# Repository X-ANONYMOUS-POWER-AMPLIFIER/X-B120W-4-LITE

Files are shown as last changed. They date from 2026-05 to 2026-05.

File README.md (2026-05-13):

# X-B120W-4-LITE - SIMPLE MAIN-CIRCUIT MODULE OF 120 WATTS CLASS-B AUDIO POWER AMPLIFIER MAIN-CIRCUIT FOR 4-OHMS OUTPUT LOAD

X-B120W-4-LITE is a power amplifier main-circuit module designed to be simple, with only few number of transistors within its input-stage and its VAS, designed to be fit in a small size single-sided circuit board. It is designed to handle 120 watts of 4-ohms output load power rating.

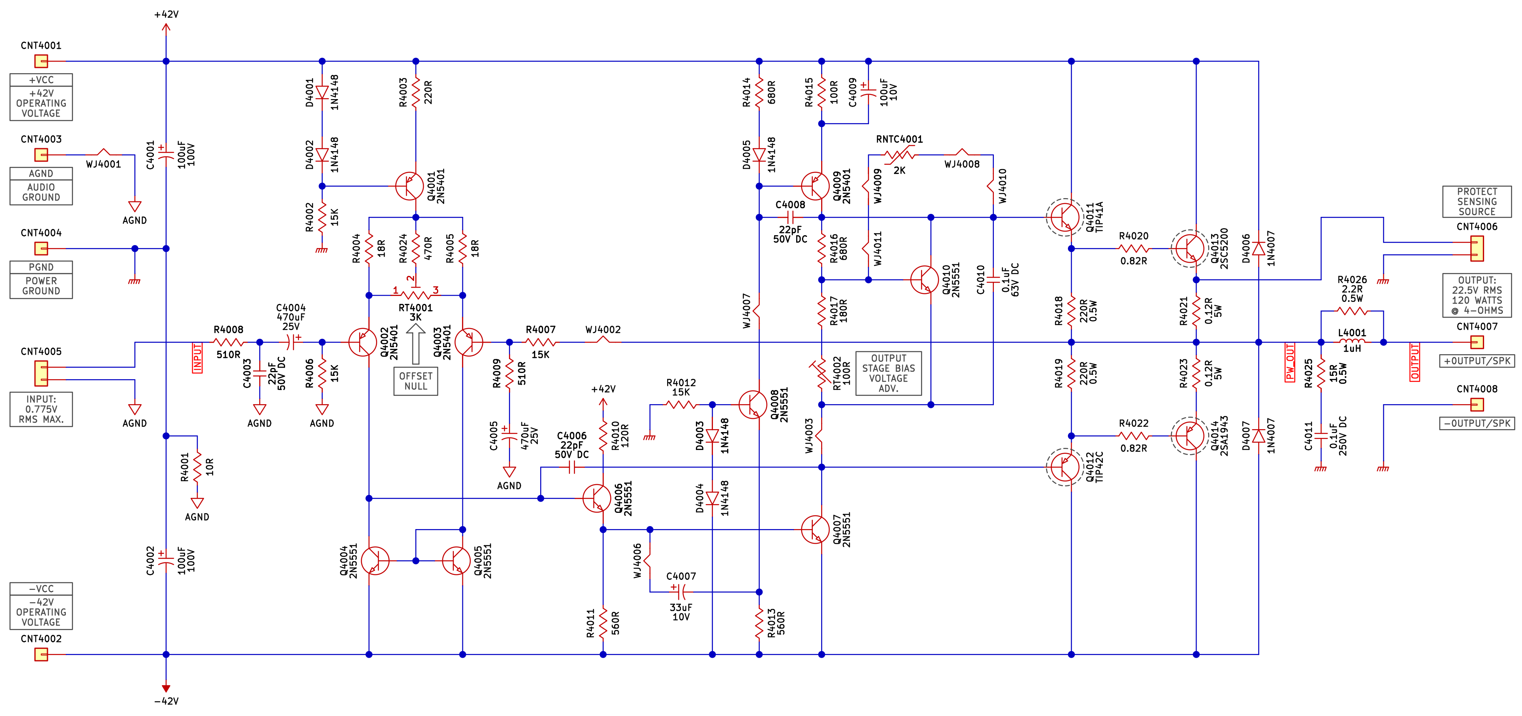
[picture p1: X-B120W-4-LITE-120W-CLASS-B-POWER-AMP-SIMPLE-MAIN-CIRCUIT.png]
X-B120W-4 schematic diagram


The circuit of X-B120W-4-LITE applies only the effective circuitry models for each of its blocks. Its input-stage applies a minimalist-but-effective LTP (Long Tailed Pair) circuit model, completed with an active-load and an offset null adjustment trimmer. Its VAS (Voltage Amplifier Stage) applies a simple circuit model but with an advanced active-load technique to achieve high amplification performance, with applies only few number of transistors without needing to apply differential-based topology.

## Advanced VAS Model

The VAS of this power amp main-circuit model has an active load that synchronized with the main VAS side to be working as well a fully symmetrical VAS. The output signal from the LTP buffer (Q4006's emitter) copied by a grounded-base transistor amplifier or signal-current-buffer, Q4008, to feed a copy of signal for VAS's loader, Q4009, makes the VAS's loader to be fully actively working side-by-side with the main VAS, Q4007.

The amplification workflow between LTP buffer, Q4006, into the VAS loader, Q4009, isn't for tackling the DC amplification, but limited for tackling AC amplification. The LTP buffer output, Q4006's emitter, is coupled by C4007 into the emitter of Q4008 for gaining the AC signal only, thus Q4008 can keep its main function as a current-source to provide a constant forward-bias-current for Q4009's base and thus Q4009 also kept its function as a current-source for providing the initial constant forward-bias-current for the output-stage while it is also taking function as an active loader of VAS for providing fully symmetrical AC amplification.

By applying this technique, this power amp main-circuit model will be able to achieve wide headroom even for 1-ohms load in fully symmetrically and certainly achieve high performance in nominal output load (4-ohms or 8-ohms). And certainly, one of the important tings is about limit the number of transistors, makes the X-B120W-4-LITE circuit model quit simple with high performance guarantee.

## Warning: None of Current-Limiter Applied Within The Output-Stage

There is none of current-limiter applied within the output-stage, means that it may introduce a risk of short-circuited output. To prevent a fatal output short-circuited overcome, an output protection circuit have to be applied between the X-B120W-4-LITE module's +SPK output and the loudspeaker. The sensing signal of the overload output or output short-circuit can be obtained via CNT4006.

You may have a question, why none of current-limiter applied within the output-stage? The answer is: Applying the current-limiters within the output-stage, as it commonly applied "just to drop the signal amplitude of the output-stage driver transistor bases" - is not really effective since the VAS will always maintain its signal-current along to follow its amplification level although the current-limiter actives as it detects a short-circuited output.

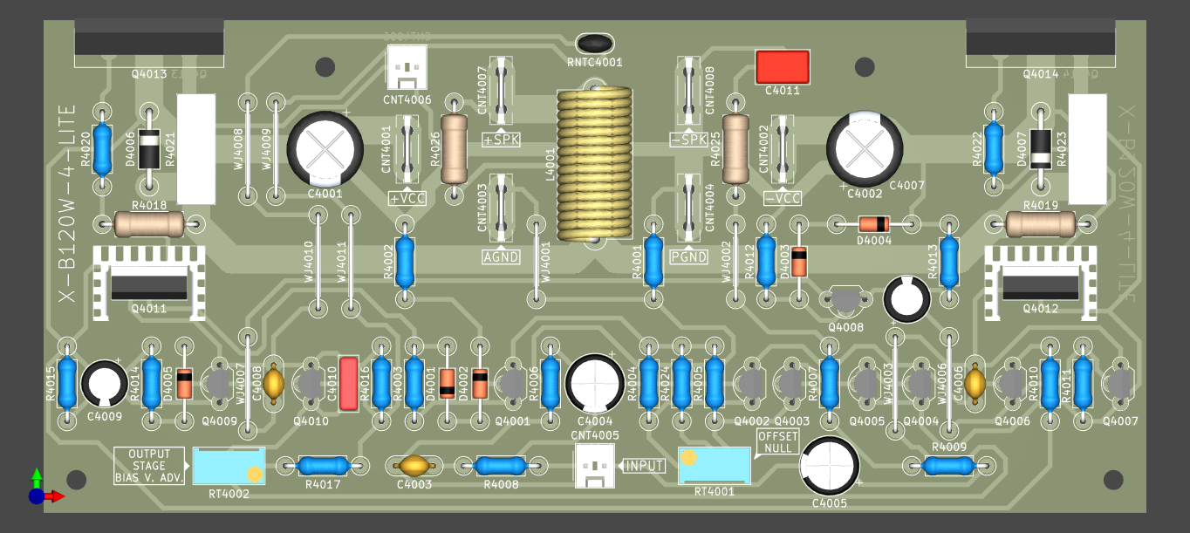
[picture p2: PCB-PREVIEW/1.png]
Circuit board preview 1

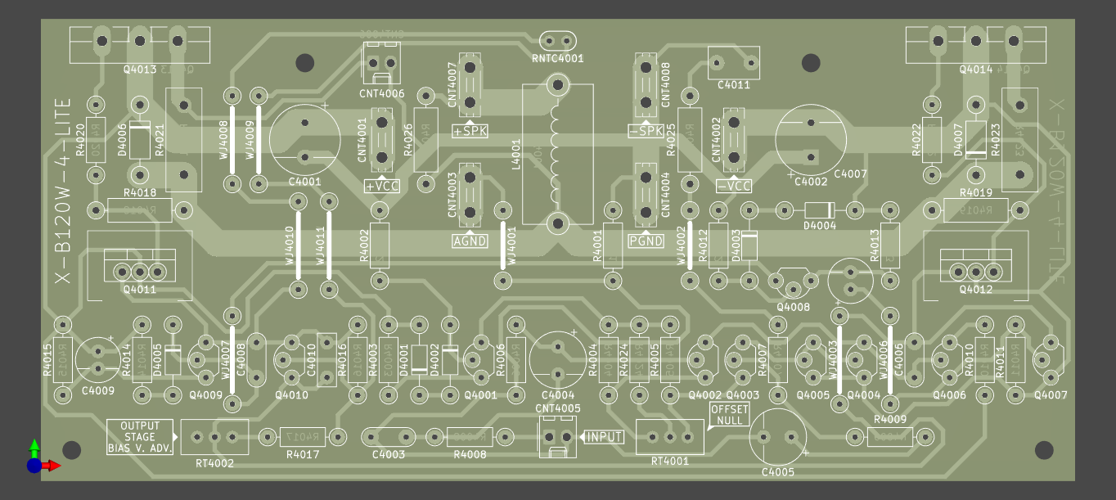
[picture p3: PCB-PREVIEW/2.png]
Circuit board preview 2

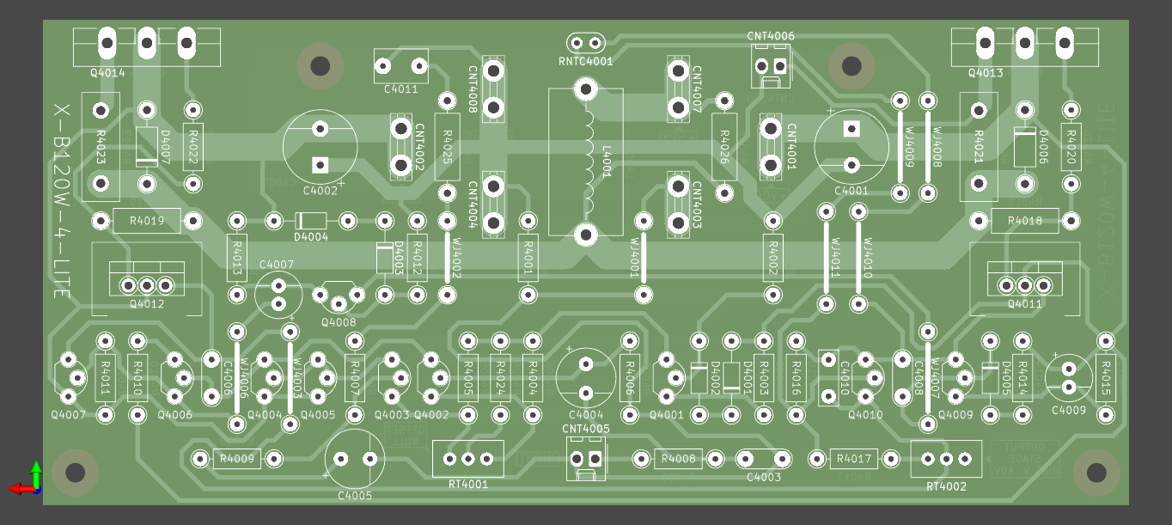
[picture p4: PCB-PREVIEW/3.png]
Circuit board preview 3

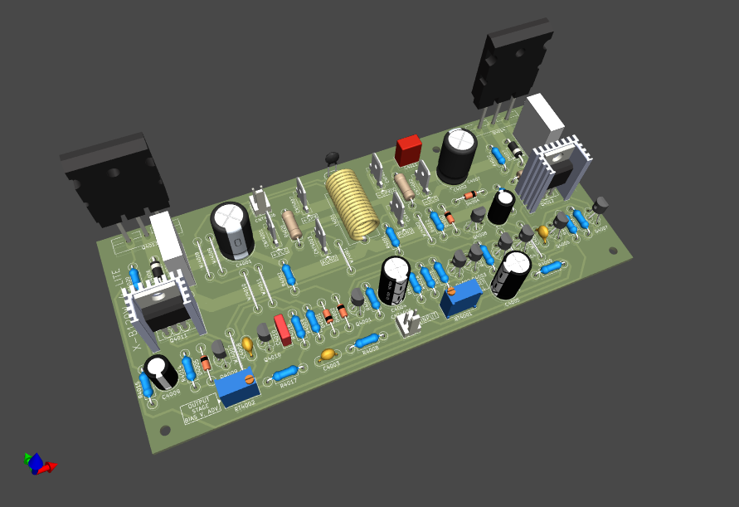
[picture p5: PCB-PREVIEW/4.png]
Circuit board preview 4

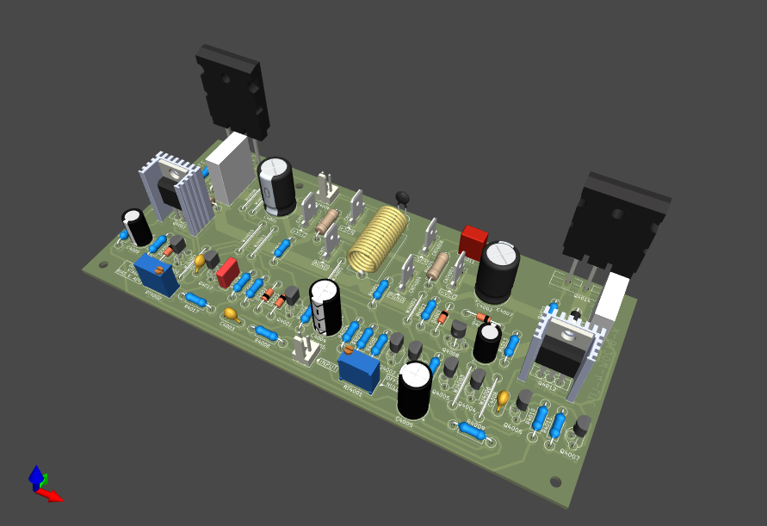
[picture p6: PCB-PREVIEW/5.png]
Circuit board preview 5


## License

1. **License Grant**  
The Licensor hereby grants you a worldwide, royalty-free, non-exclusive, perpetual license to use the circuit design for the non-commercial purposes only.
2. **Conditions**  
Attribution: You must provide credit to the original creator when distributing this circuit design.
3. **Disclaimer of Warranty**  
THE DESIGN IS PROVIDED "AS IS". THE LICENSOR MAKES NO WARRANTIES, EXPRESS OR IMPLIED, REGARDING THE DESIGN, INCLUDING BUT NOT LIMITED TO ANY IMPLIED WARRANTIES OF MERCHANTABILITY OR FITNESS FOR A PARTICULAR PURPOSE.
4. **Limitation of Liability**  
IN NO EVENT SHALL THE LICENSOR BE LIABLE FOR ANY DAMAGES, INCLUDING BUT NOT LIMITED TO DIRECT, INDIRECT, INCIDENTAL, OR CONSEQUENTIAL DAMAGES ARISING OUT OF THE USE OF THE DESIGN.

# Design Files Bundle Download

Design files bundle is available for download by follow the URL: [https://github.com/X-ANONYMOUS-POWER-AMPLIFIER/X-B120W-4-LITE/archive/refs/heads/main.zip](https://github.com/X-ANONYMOUS-POWER-AMPLIFIER/X-B120W-4-LITE/archive/refs/heads/main.zip)

The main design files of schematic and PCB design are in [KiCad](https://www.kicad.org/) V.9.x format.

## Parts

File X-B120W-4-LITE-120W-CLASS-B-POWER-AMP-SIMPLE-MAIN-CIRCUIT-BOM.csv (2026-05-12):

Reference | Value | Rating | Description | MFR Number | Manufacturer | Qty
C4001,C4002 | 100uF | 100V | Aluminum Electrolytic Capacitors - Radial Leaded 100uF 100V | ECA-1EM100I | Panasonic | 2
C4003,C4006,C4008 | 22pF | 50V DC | Multilayer Ceramic Capacitors MLCC - Leaded 22PF 50V 5% 5.0MM | RDE5C1H220J0K1H03B | Murata | 3
C4004,C4005 | 470uF | 25V | Aluminum Electrolytic Capacitors - Radial Leaded 470uF 25V | EEU-FC1E471L | Panasonic | 2
C4007 | 33uF | 10V | Aluminum Electrolytic Capacitors - Radial Leaded 10VDC 33uF POLARIZED | ECE-A1AKS330I | Panasonic | 1
C4009 | 100uF | 10V | Aluminum Electrolytic Capacitors - Radial Leaded 100uF 10V | ECE-A1AKA101 | Panasonic | 1
C4010 | 0.1uF | 63V DC | Film Capacitors 0.1 uF 63 VDC 5% | MKS2C031001A00JI00 | WIMA | 1
C4011 | 0.1uF | 250V DC | Film Capacitors 0.1 uF 250 VDC 20% | MKS2F031001E00MSSD | WIMA | 1
CNT4001,CNT4002,CNT4003,CNT4004,CNT4007,CNT4008 | 2376582-2 |  | 250 FASTON PCB TAB TPBR | 2376582-2 | TE Connectivity | 6
CNT4005,CNT4006 | 22-27-2021 |  | Headers & Wire Housings 2 POS HEADER | 22-27-2021 | Molex | 2
D4001,D4002,D4003,D4004,D4005 | 1N4148 |  | Small Signal Switching Diodes Small Signal Diode, DO-35, 100V, 0.2A, 175C | 1N4148 | Diotec Semiconductor | 5
D4006,D4007 | 1N4007 |  | Rectifiers Diode, DO-41, 1000V, 1A | 1N4007 | Diotec Semiconductor | 2
L4001 | 1uH |  | Air Core Inductor, 16 windings, D = 8 mm, enameled wire diameter = 1.2 mm |  |  | 1
Q4001,Q4002,Q4003,Q4009 | 2N5401 |  | Bipolar Transistors - BJT PNP 160Vcbo 150Vceo 5.0Vebo 600mA 625mW | 2N5401 TIN/LEAD | Central Semiconductor | 4
Q4004,Q4005,Q4006,Q4007,Q4008,Q4010 | 2N5551 |  | Bipolar Transistors - BJT NPN 180Vcbo 160Vceo 6.0Vebo 600mA 625mW\ | 2N5551 TIN/LEAD | Central Semiconductor | 6
Q4011 | TIP41A |  | Bipolar Transistors - BJT 6A 100V 65W NPN | TIP41C | STMicroelectronics | 1
Q4012 | TIP42C |  | Bipolar Transistors - BJT 6A 100V 65W PNP | TIP42C | STMicroelectronics | 1
Q4013 | 2SC5200 |  | Bipolar Transistors - BJT NPN 230V 15A | 2SC5200-O(Q) | Toshiba | 1
Q4014 | 2SA1943 |  | Bipolar Transistors - BJT PNP 230V 15A | 2SA1943-O(Q) | Toshiba | 1
R4001 | 10R | 0.25W | Metal Film Resistors - Through Hole 10 OHM 1/4W 1% | MFR-25FRE52-10R | YAGEO | 1
R4002,R4006,R4007,R4012 | 15K | 0.25W | Metal Film Resistors - Through Hole 15K OHM 1/4W 1% | MFR-25FRE52-15K | YAGEO | 4
R4003 | 220R | 0.25W | Metal Film Resistors - Through Hole 220 OHM 1/4W 1% | MFR-25FRE52-220R | YAGEO | 1
R4004,R4005 | 18R | 0.25W | Metal Film Resistors - Through Hole 18 OHM 1/4W 1% | MFR-25FRE52-18R | YAGEO | 2
R4008,R4009 | 510R | 0.25W | Metal Film Resistors - Through Hole 510 OHM 1/4W 1% | MFR-25FRE52-510R | YAGEO | 2
R4010 | 120R | 0.25W | Metal Film Resistors - Through Hole 120 OHM 1/4W 1% | MFR-25FRE52-120R | YAGEO | 1
R4011,R4013 | 560R | 0.25W | Metal Film Resistors - Through Hole 560 OHM 1/4W 1% | MFR-25FRE52-560R | YAGEO | 2
R4014,R4016 | 680R | 0.25W | Metal Film Resistors - Through Hole 680 OHM 1/4W 1% | MFR-25FRE52-680R | YAGEO | 2
R4015 | 100R | 0.25W | Metal Film Resistors - Through Hole 100 OHM 1/4W 1% | MFR-25FRE52-100R | YAGEO | 1
R4017 | 180R | 0.25W | Metal Film Resistors - Through Hole 180 OHM 1/4W 1% | MFR-25FRE52-180R | YAGEO | 1
R4018,R4019 | 220R | 0.5W | Metal Film Resistors - Through Hole 220 OHM 1/5W 1% | MFR-50FTE52-220R | YAGEO | 2
R4020,R4022 | 0.82R | 0.25W | Metal Oxide Resistors RSS1/2 .82 5%TR | MOSX1/2CT52RR82J | KOA Speer | 2
R4021,R4023 | 0.12R | 5W | Current Sense Resistors - Through Hole 0.12 Ohm 5W 5% 350ppm | BPR58CR12J | KOA Speer | 2
R4024 | 470R | 0.25W | Metal Film Resistors - Through Hole 510 OHM 1/4W 1% | MFR-25FRE52-510R | YAGEO | 1
R4025 | 15R | 0.5W | Metal Film Resistors - Through Hole 15 OHM 1/5W 1% | MFR-50FTE52-15R | YAGEO | 1
R4026 | 2.2R | 0.5W | Metal Film Resistors - Through Hole 2.2 OHM 1/5W 1% | MFR-50FTE52-2R2 | YAGEO | 1
RNTC4001 | 2K |  | NTC Thermistors 2Kohm/2% 3528/0.5% | NTCLE100E3202GB0A | Vishay / BC Components | 1
RT4001 | 3K |  | Trimmer Resistors - Through Hole 3/8" 3Kohms Sealed Vertical Adjust | 3296W-1-302ALF | Bourns | 1
RT4002 | 100R |  | Trimmer Resistors - Through Hole 3/8" 100 ohms Sealed Vertical Adjust | 3296W-1-101ALF | Bourns | 1
WJ4001,WJ4002,WJ4003,WJ4006,WJ4007,WJ4008,WJ4009,WJ4010,WJ4011 | Wire Jumper |  | Wire Jumper |  |  | 9

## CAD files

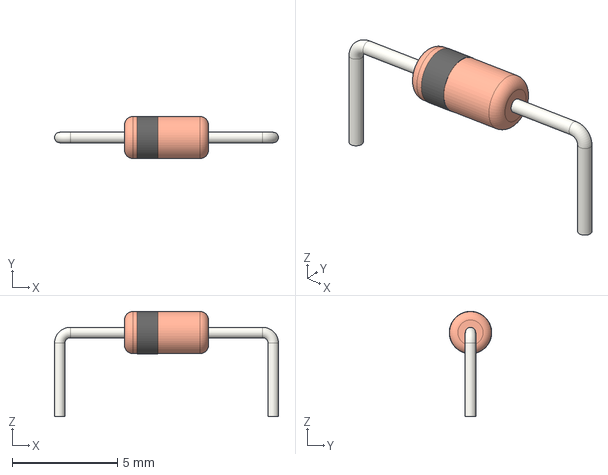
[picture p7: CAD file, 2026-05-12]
3D-FOOTPRINTS/D_DO-35_SOD27_P10.16mm_Horizontal.step
10.7 x 2.02 x 5.01 mm

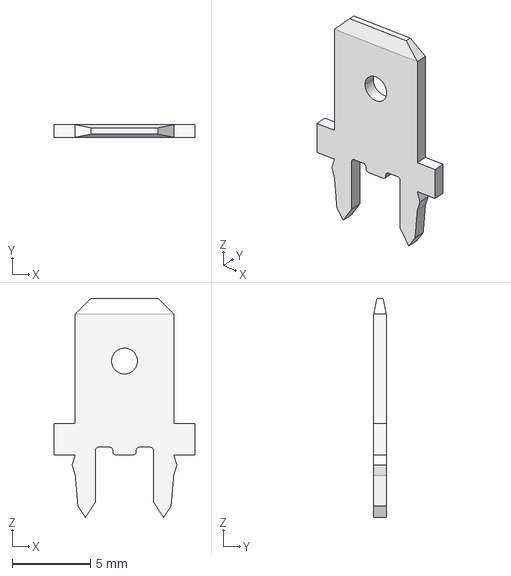
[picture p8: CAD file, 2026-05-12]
3D-FOOTPRINTS/c-2376582-2-a-3d.stp
9.00 x 0.8 x 14.0 mm

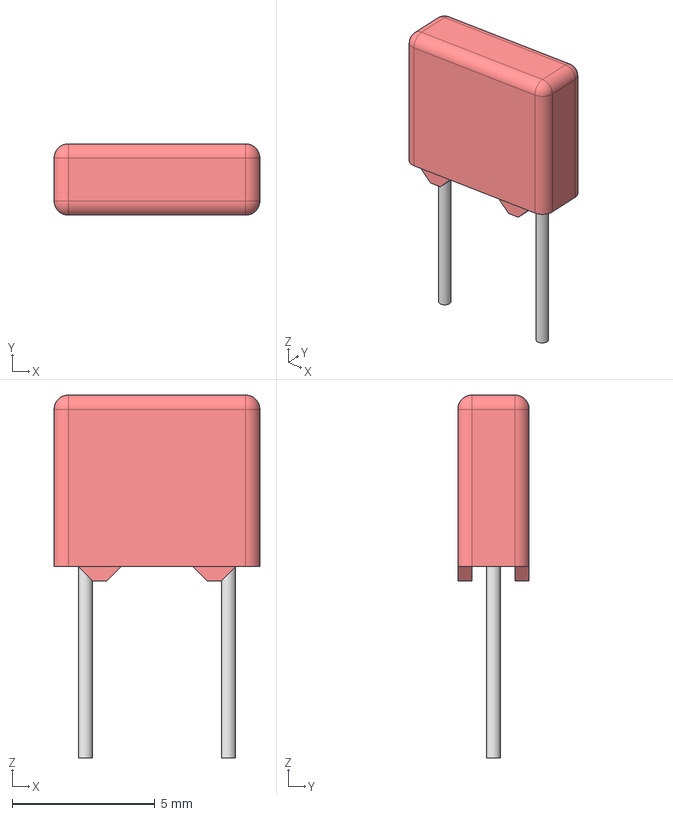
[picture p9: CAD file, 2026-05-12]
3D-FOOTPRINTS/FILM_RED_P500L720W250H650PD50.step
7.20 x 2.50 x 12.7 mm

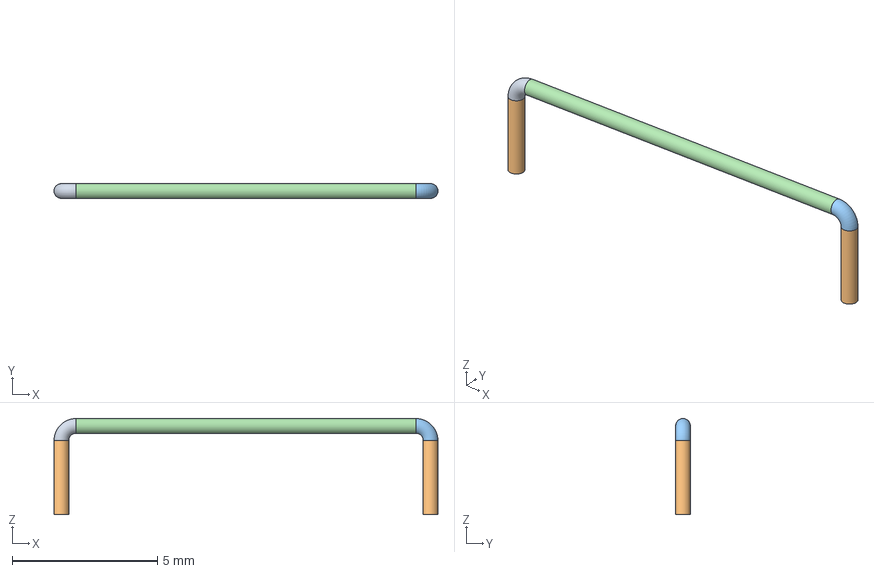
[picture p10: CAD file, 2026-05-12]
3D-FOOTPRINTS/J_12.7mm.step
13.2 x 0.508 x 3.30 mm

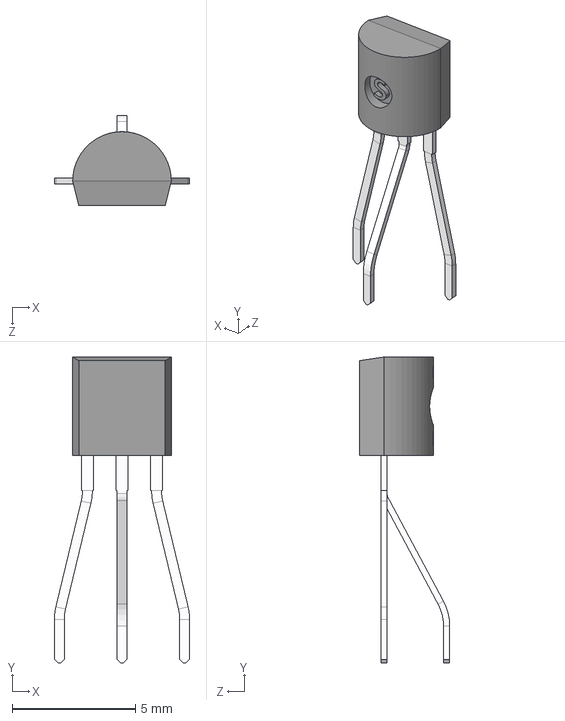
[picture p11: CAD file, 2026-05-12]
3D-FOOTPRINTS/TO-92.STEP
5.48 x 12.4 x 3.66 mm

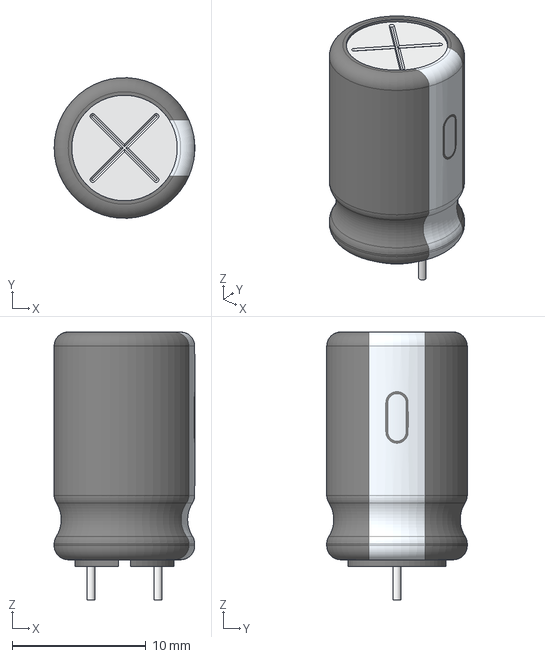
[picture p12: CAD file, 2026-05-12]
3D-FOOTPRINTS/CAP_RAD_D10x16_POL_BK.stp
10.5 x 10.5 x 20.0 mm

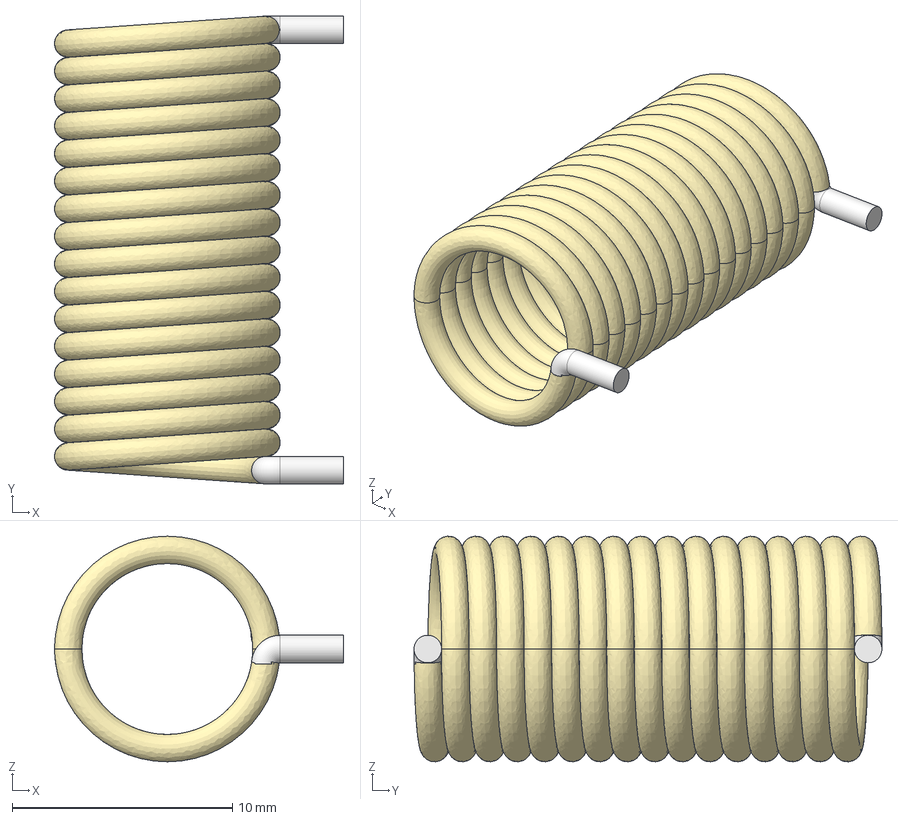
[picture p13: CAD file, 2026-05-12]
3D-FOOTPRINTS/INDUCTOR_AIR_CORE_1uH.step
13.1 x 21.2 x 10.2 mm
Slice.0

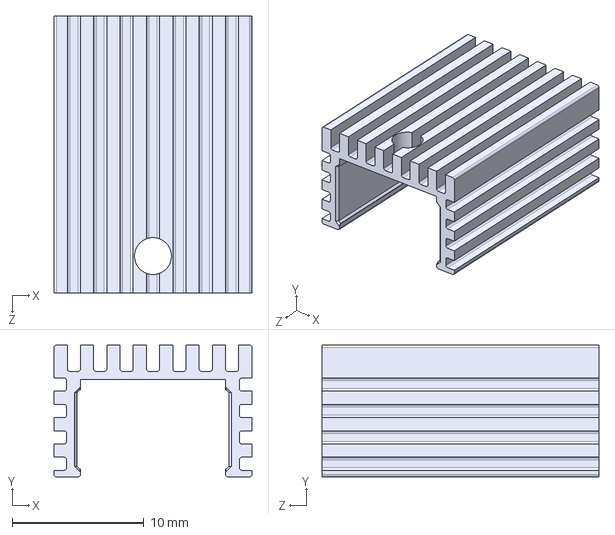
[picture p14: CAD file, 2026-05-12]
3D-FOOTPRINTS/TO220 Heatsink.STEP
15.0 x 10.0 x 21.0 mm

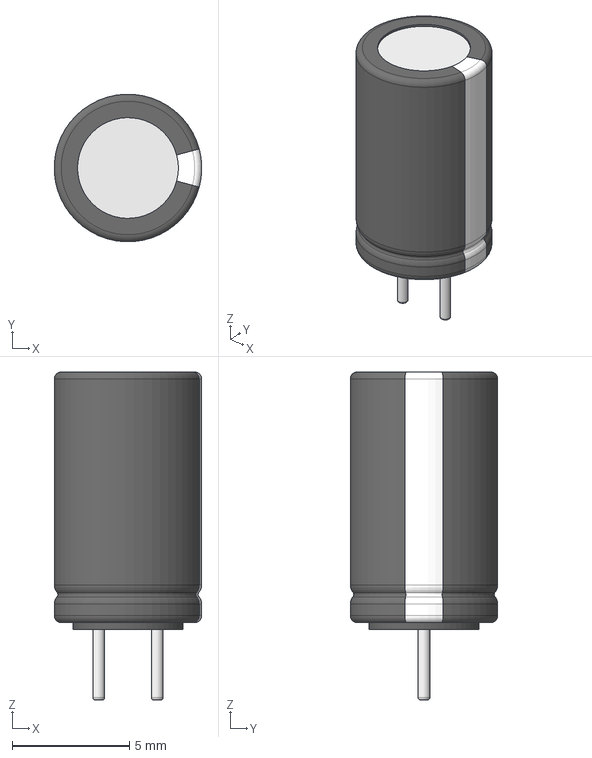
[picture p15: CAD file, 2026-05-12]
3D-FOOTPRINTS/Aluminum_electrolytic_capacitor_radial_D6.3_H11_PinD0.5_Pitch2.5_nominal_black.step
6.29 x 6.30 x 14.0 mm

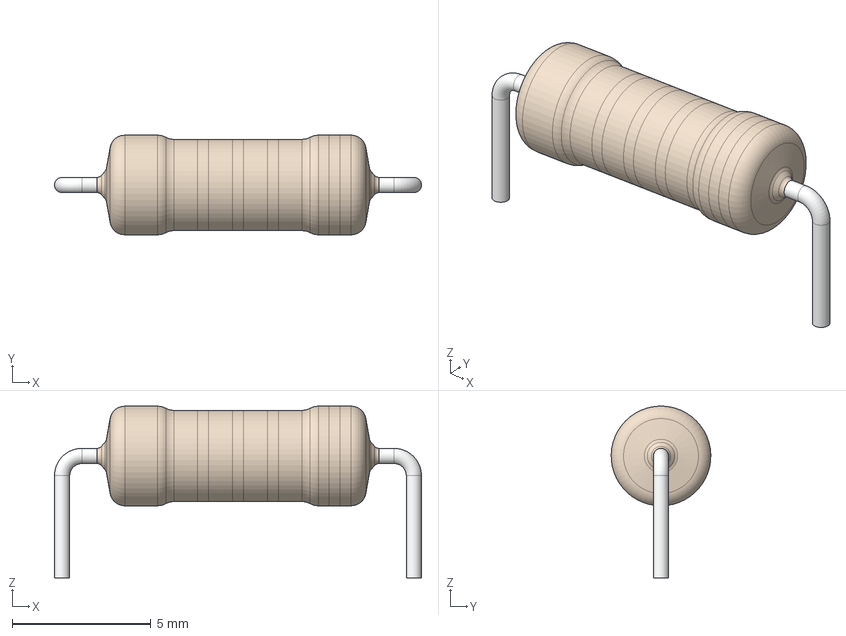
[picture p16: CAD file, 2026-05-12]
3D-FOOTPRINTS/RES-0.5W-H-MO.stp
13.2 x 3.60 x 6.20 mm
RES-0.5W-H-MO
RES-0.5W-H-MO001
RES-0.5W-H-MO002

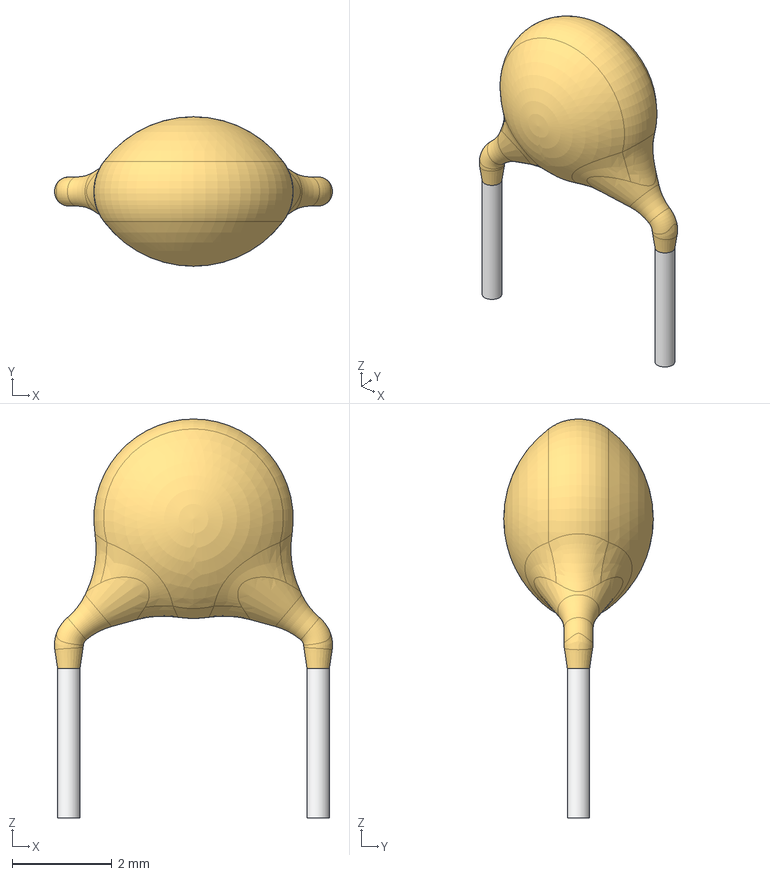
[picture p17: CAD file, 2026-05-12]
3D-FOOTPRINTS/CAP_DISC_4x3_YL.stp
5.58 x 3.00 x 8.00 mm
CAP_DISC_4x3_YL
CAP_DISC_4x3_YL001
CAP_DISC_4x3_YL002

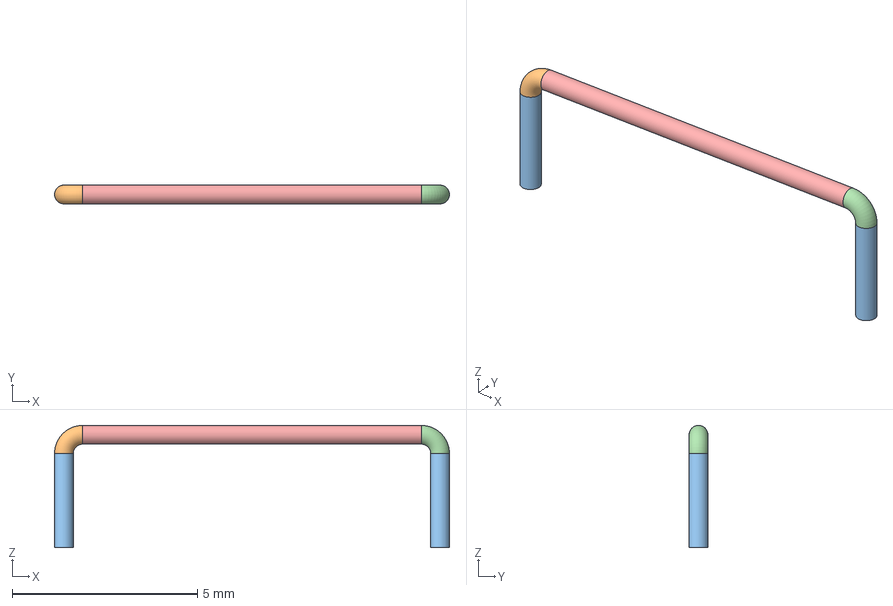
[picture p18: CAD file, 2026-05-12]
3D-FOOTPRINTS/J_10.16mm.step
10.7 x 0.508 x 3.30 mm
Circle
Arc
Circle003
Line
Circle004
Arc001
Circle005
Line002
Circle002
Line001

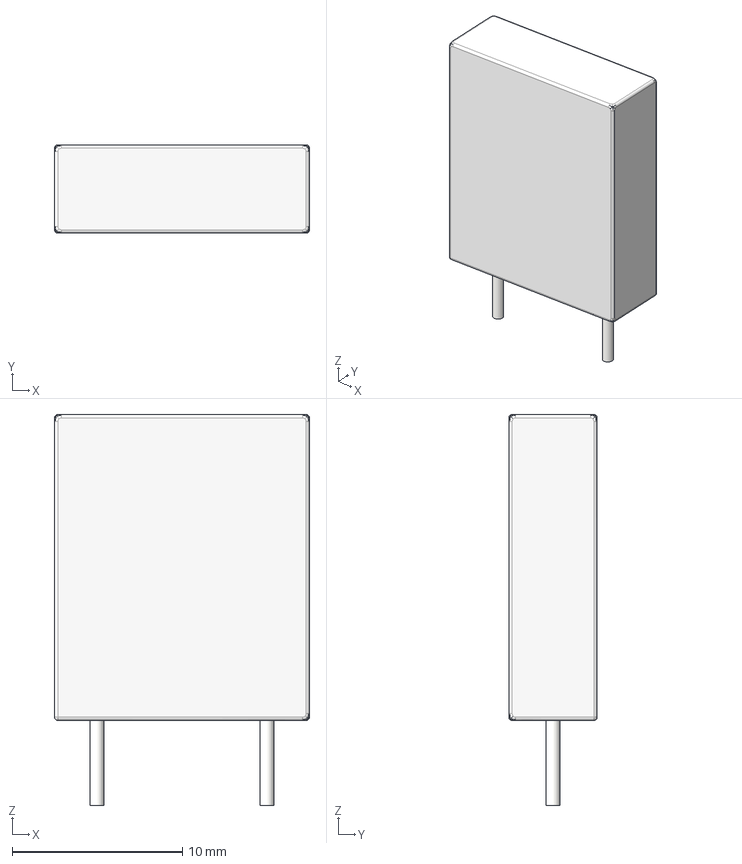
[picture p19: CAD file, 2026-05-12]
3D-FOOTPRINTS/BPR-cement-resistor.step
15.0 x 5.20 x 23.0 mm

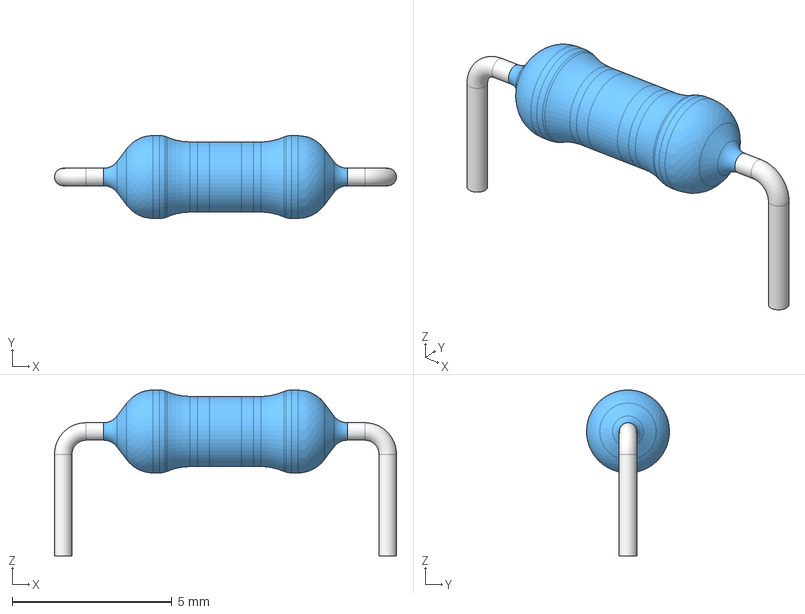
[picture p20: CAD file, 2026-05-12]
3D-FOOTPRINTS/RES-0.25W-H-CF.stp
10.7 x 2.60 x 5.20 mm
RES-0.25W-H-CF
RES-0.25W-H-CF001
RES-0.25W-H-CF002

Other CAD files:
3D-FOOTPRINTS/NTC.step
3D-FOOTPRINTS/470uF 25V electr 8 x16mm -P.diameter 4mm-Black-White.stp

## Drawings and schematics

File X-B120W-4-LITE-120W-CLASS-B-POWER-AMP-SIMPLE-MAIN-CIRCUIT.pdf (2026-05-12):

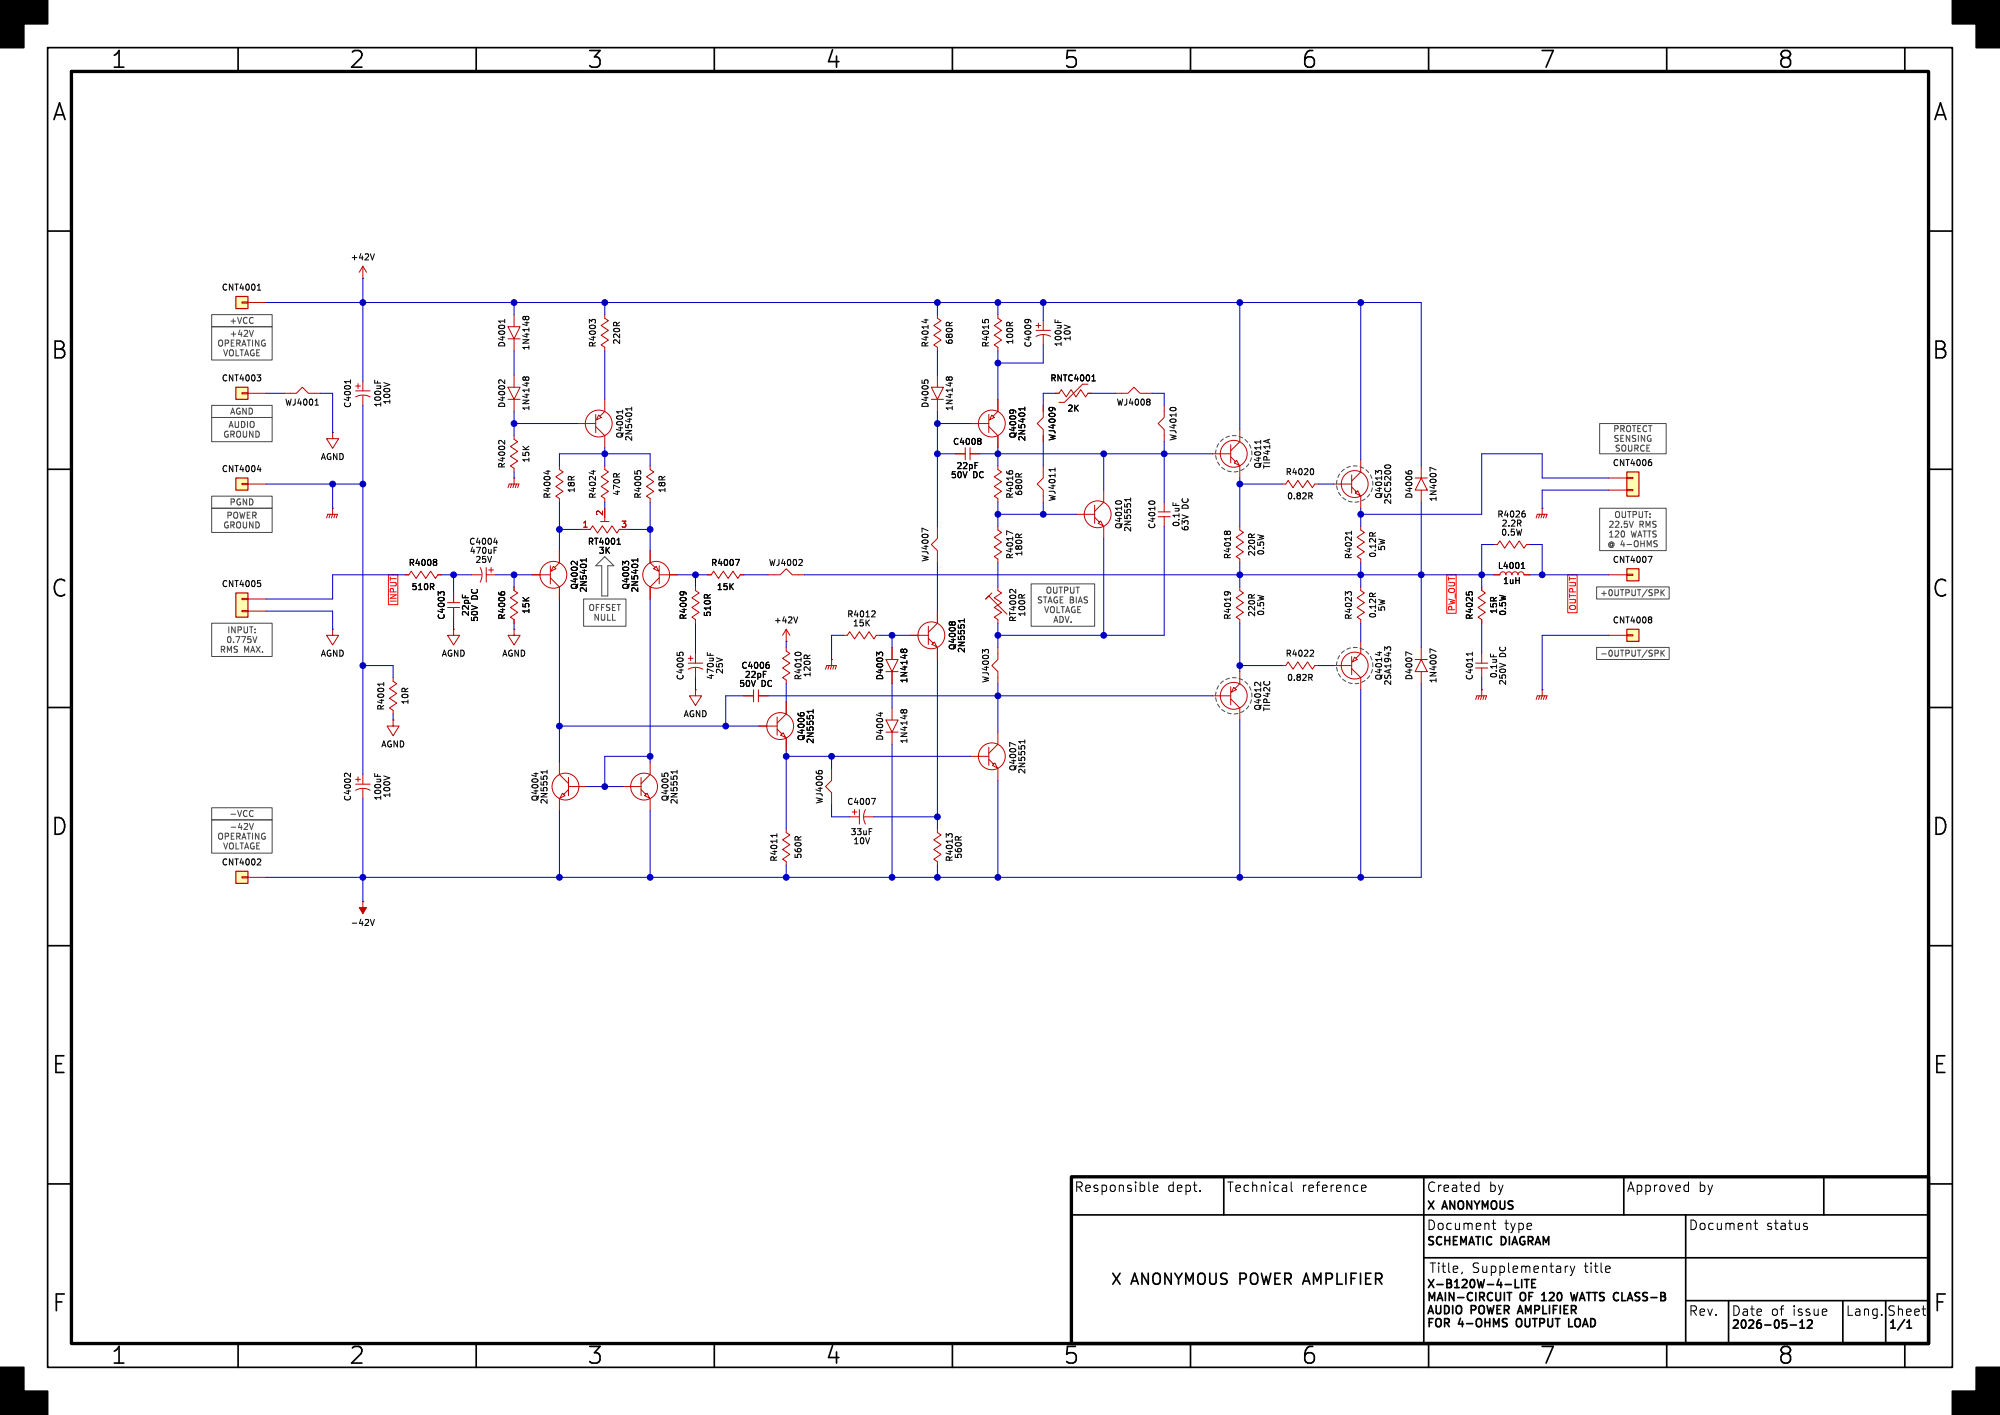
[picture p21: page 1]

INPUT: 0.775V RMS MAX. +42V OPERATING

SOURCE OUTPUT STAGE BIAS

X ANONYMOUS

SCHEMATIC DIAGRAM

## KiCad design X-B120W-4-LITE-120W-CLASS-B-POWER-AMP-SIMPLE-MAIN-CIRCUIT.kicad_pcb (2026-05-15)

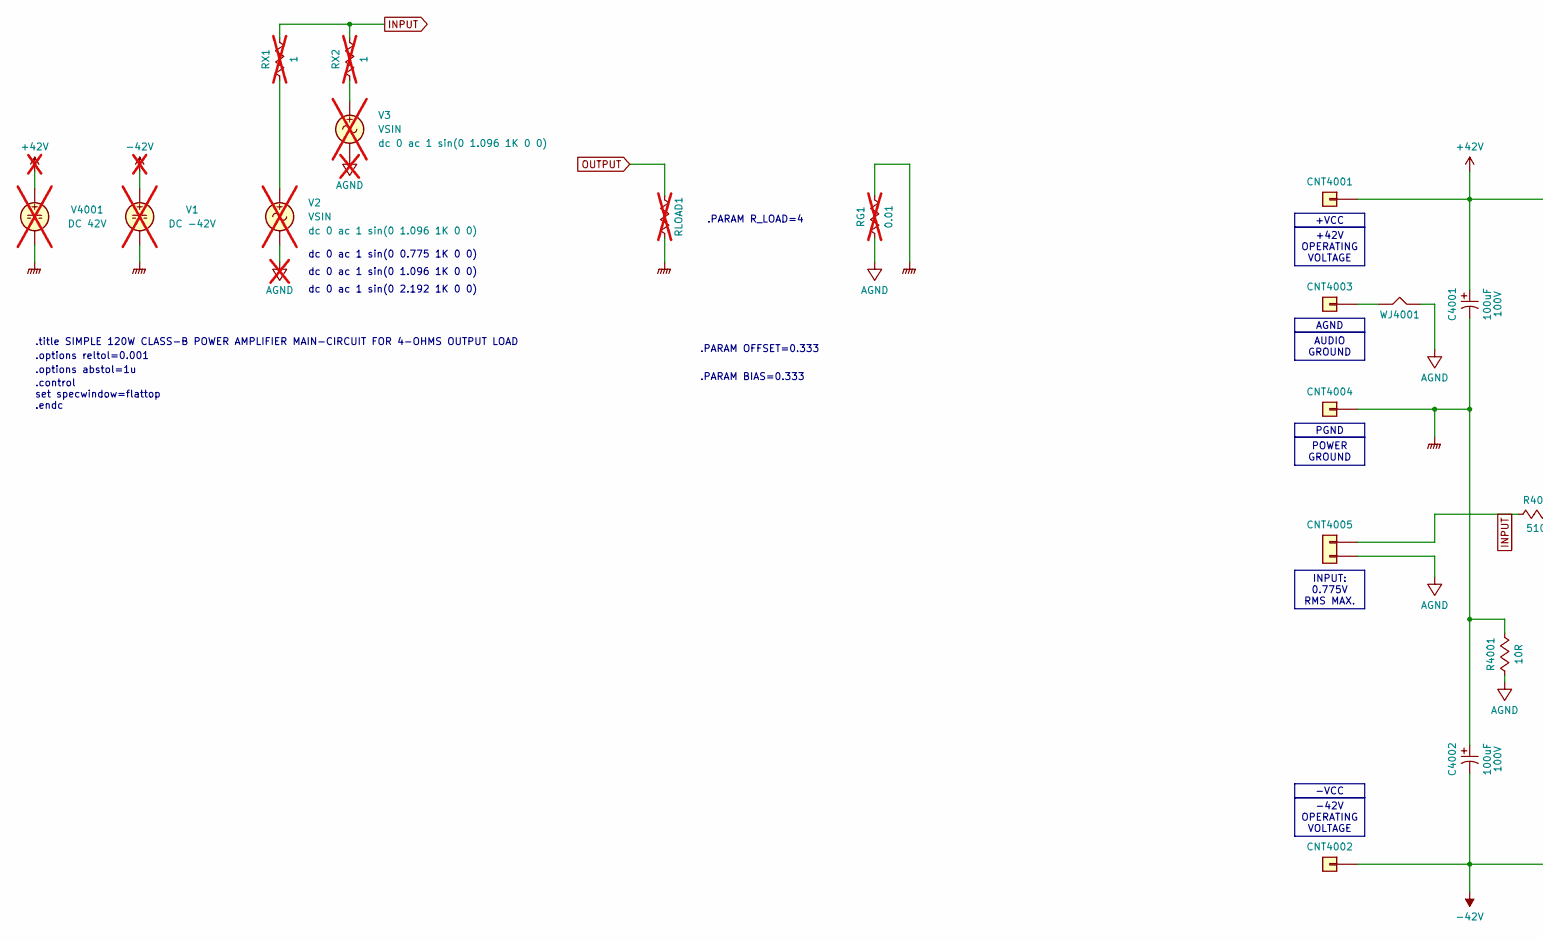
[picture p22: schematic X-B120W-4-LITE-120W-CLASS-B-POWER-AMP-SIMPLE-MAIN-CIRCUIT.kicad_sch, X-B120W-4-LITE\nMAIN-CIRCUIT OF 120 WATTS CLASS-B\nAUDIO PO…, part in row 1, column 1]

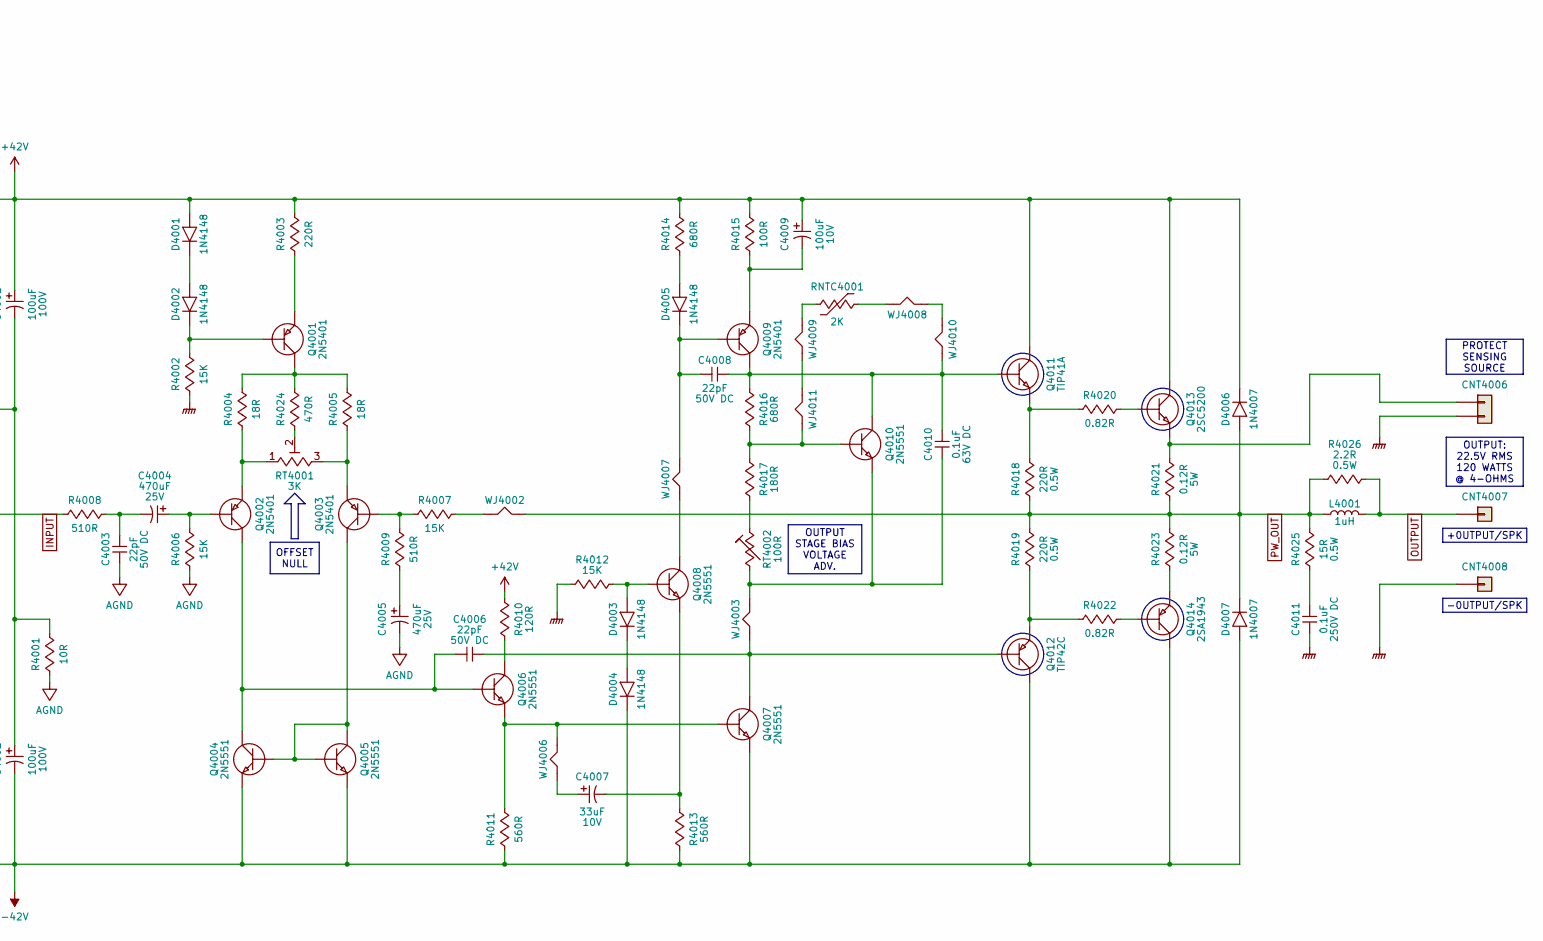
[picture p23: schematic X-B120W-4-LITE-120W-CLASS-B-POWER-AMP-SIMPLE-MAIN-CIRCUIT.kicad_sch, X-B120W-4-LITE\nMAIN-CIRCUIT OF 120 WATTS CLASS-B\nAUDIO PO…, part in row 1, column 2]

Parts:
C4001, C4002: 100uF; CP_Radial_D10.0mm_P5.00mm; Rating 100V
C4003, C4006, C4008: 22pF; C_Disc_D7.5mm_W2.5mm_P5.08mm; Rating 50V DC
C4004, C4005: 470uF; CP_Radial_D8.0mm_P4.00mm_P5.00mm; Rating 25V
C4007: 33uF; CP_Radial_D6.3mm_P2.50mm; Rating 10V
C4009: 100uF; CP_Radial_D6.3mm_P2.50mm; Rating 10V
C4010: 0.1uF; C_Rect_L7.5mm_W2.5mm_P5.00mm_WIMA_MKS2; Rating 63V DC
C4011: 0.1uF; C_Rect_L7.2mm_W4.5mm_P5.00mm_FKS2_FKP2_MKS2_MKP2; Rating 250V DC
CNT4001, CNT4002, CNT4003, CNT4004, CNT4007, CNT4008: 2376582-2; PCB_TAB_250_FASTON_TPBR
CNT4005, CNT4006: 22-27-2021; Molex_KK-254_AE-6410-02A_1x02_P2.54mm_Vertical
D4001, D4002, D4003, D4004, D4005: 1N4148; D_DO-35_SOD27_P10.16mm_Horizontal
D4006, D4007: 1N4007; D_DO-41_SOD81_P10.16mm_Horizontal
L4001: 1uH; Inductor_Air_Core_1uH
Q4001, Q4002, Q4003, Q4009: 2N5401; TO-92_3_Wide
Q4004, Q4005, Q4006, Q4007, Q4008, Q4010: 2N5551; TO-92_3_Wide
Q4011: TIP41A; TO-220-3_Vertical_With_Small_Heatsink
Q4012: TIP42C; TO-220-3_Vertical_With_Small_Heatsink
Q4013: 2SC5200; TO-264-3_Vertical
Q4014: 2SA1943; TO-264-3_Vertical
R4001: 10R; R_Axial_DIN0207_L6.3mm_D2.5mm_P10.16mm; Rating 0.25W
R4002, R4006, R4007, R4012: 15K; R_Axial_DIN0207_L6.3mm_D2.5mm_P10.16mm; Rating 0.25W
R4003: 220R; R_Axial_DIN0207_L6.3mm_D2.5mm_P10.16mm; Rating 0.25W
R4004, R4005: 18R; R_Axial_DIN0207_L6.3mm_D2.5mm_P10.16mm; Rating 0.25W
R4008, R4009: 510R; R_Axial_DIN0207_L6.3mm_D2.5mm_P10.16mm; Rating 0.25W
R4010: 120R; R_Axial_DIN0207_L6.3mm_D2.5mm_P10.16mm; Rating 0.25W
R4011, R4013: 560R; R_Axial_DIN0207_L6.3mm_D2.5mm_P10.16mm; Rating 0.25W
R4014, R4016: 680R; R_Axial_DIN0207_L6.3mm_D2.5mm_P10.16mm; Rating 0.25W
R4015: 100R; R_Axial_DIN0207_L6.3mm_D2.5mm_P10.16mm; Rating 0.25W
R4017: 180R; R_Axial_DIN0207_L6.3mm_D2.5mm_P10.16mm; Rating 0.25W
R4018, R4019: 220R; R_Axial_DIN0309_L9.0mm_D3.2mm_P12.70mm; Rating 0.5W
R4020, R4022: 0.82R; R_Axial_DIN0207_L6.3mm_D2.5mm_P10.16mm; Rating 0.25W
R4021, R4023: 0.12R; R_BPR_5W; Rating 5W
R4024: 470R; R_Axial_DIN0207_L6.3mm_D2.5mm_P10.16mm; Rating 0.25W
R4025: 15R; R_Axial_DIN0309_L9.0mm_D3.2mm_P12.70mm; Rating 0.5W
R4026: 2.2R; R_Axial_DIN0309_L9.0mm_D3.2mm_P12.70mm; Rating 0.5W
RG1: 0.01; R_Axial_DIN0207_L6.3mm_D2.5mm_P10.16mm; Rating 0.25W; not fitted
RLOAD1: r={R_LOAD}; R_Axial_DIN0207_L6.3mm_D2.5mm_P10.16mm; Rating 0.25W; not fitted
RNTC4001: 2K; NTC_D5.0mm_T2.5mm_SP2.50mm_Flip_Mount
RT4001: 3K; Potentiometer_Bourns_3296W_Vertical
RT4002: 100R; Potentiometer_Bourns_3296W_Vertical
RX1, RX2: 1; R_Axial_DIN0207_L6.3mm_D2.5mm_P10.16mm; Rating 0.25W; not fitted
V1: DC -42V; not fitted
V2, V3: VSIN; not fitted
V4001: DC 42V; not fitted
WJ4001, WJ4002: Wire Jumper; J_10.16mm
WJ4003, WJ4006, WJ4007, WJ4008, WJ4009, WJ4010, WJ4011: Wire Jumper; J_12.7mm

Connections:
0: C4001.2, C4002.1, C4011.2, CNT4004.1, CNT4006.2, CNT4008.1, R4001.1, R4002.2, R4012.1, RG1.1, RLOAD1.2, V1.2, V4001.2
+42V: C4001.1, C4009.1, CNT4001.1, D4001.2 (A), D4006.1 (K), Q4011.2 (C), Q4013.2 (C), R4003.1, R4010.1, R4014.1, R4015.1, V4001.1
-42V: C4002.2, CNT4002.1, D4004.1 (K), D4007.2 (A), Q4004.1 (E), Q4005.1 (E), Q4007.1 (E), Q4012.2 (C), Q4014.2 (C), R4011.2, R4013.2, V1.1
AGND: C4003.2, C4005.2, CNT4005.2, R4001.2, R4006.2, RG1.2, V2.2, V3.2, WJ4001.2
INPUT: CNT4005.1, R4008.2, RX1.1, RX2.1
unnamed: C4003.1, C4004.2, R4008.1
unnamed: C4005.1, R4009.2
unnamed: C4007.1, WJ4006.1
unnamed: C4011.1, R4025.2
unnamed: CNT4003.1, WJ4001.1
unnamed: CNT4006.1, Q4013.3 (E), R4021.1
unnamed: D4001.1 (K), D4002.2 (A)
unnamed: D4002.1 (K), Q4001.2 (B), R4002.1
unnamed: D4003.2 (A), Q4008.2 (B), R4012.2
unnamed: D4003.1 (K), D4004.2 (A)
unnamed: D4005.2 (A), R4014.2
unnamed: C4008.2, D4005.1 (K), Q4009.2 (B), WJ4007.2
unnamed: Q4001.3 (C), R4004.1, R4005.1, R4024.1
unnamed: Q4001.1 (E), R4003.2
unnamed: C4004.1, Q4002.2 (B), R4006.1
unnamed: C4006.2, Q4002.3 (C), Q4004.3 (C), Q4006.2 (B)
unnamed: Q4002.1 (E), R4004.2, RT4001.1
unnamed: Q4003.2 (B), R4007.2, R4009.1
unnamed: Q4003.3 (C), Q4004.2 (B), Q4005.2 (B), Q4005.3 (C)
unnamed: Q4003.1 (E), R4005.2, RT4001.3
unnamed: Q4006.3 (C), R4010.2
unnamed: Q4006.1 (E), Q4007.2 (B), R4011.1, WJ4006.2
unnamed: C4006.1, Q4007.3 (C), Q4012.1 (B), WJ4003.2
unnamed: Q4008.3 (C), WJ4007.1
unnamed: C4007.2, Q4008.1 (E), R4013.1
unnamed: C4008.1, C4010.1, Q4009.3 (C), Q4010.3 (C), Q4011.1 (B), R4016.1, WJ4010.1
unnamed: C4009.2, Q4009.1 (E), R4015.2
unnamed: Q4010.2 (B), R4016.2, R4017.1, WJ4011.1
unnamed: C4010.2, Q4010.1 (E), RT4002.2, WJ4003.1
unnamed: Q4011.3 (E), R4018.1, R4020.1
unnamed: Q4012.3 (E), R4019.2, R4022.2
unnamed: Q4013.1 (B), R4020.2
unnamed: Q4014.1 (B), R4022.1
unnamed: Q4014.3 (E), R4023.2
unnamed: R4007.1, WJ4002.1
unnamed: R4017.2, RT4002.1
unnamed: R4024.2, RT4001.2
unnamed: RNTC4001.1, WJ4008.2
unnamed: RNTC4001.2, WJ4009.2
unnamed: RX1.2, V2.1
unnamed: RX2.2, V3.1
unnamed: WJ4008.1, WJ4010.2
unnamed: WJ4009.1, WJ4011.2
OUTPUT: CNT4007.1, L4001.2, R4026.1, RLOAD1.1
PW_OUT: D4006.2 (A), D4007.1 (K), L4001.1, R4018.2, R4019.1, R4021.2, R4023.1, R4025.1, R4026.2, WJ4002.2

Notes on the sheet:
.options abstol=1u
dc 0 ac 1 sin(0 2.192 1K 0 0)
.options reltol=0.001
.title SIMPLE 120W CLASS-B POWER AMPLIFIER MAIN-CIRCUIT FOR 4-OHMS OUTPUT LOAD
dc 0 ac 1 sin(0 0.775 1K 0 0)
.PARAM BIAS=0.333
.PARAM OFFSET=0.333
.PARAM R_LOAD=4
.control set specwindow=flattop .endc
dc 0 ac 1 sin(0 1.096 1K 0 0)
PROTECT SENSING SOURCE
-0UTPUT/SPK
-VCC
INPUT: 0.775V RMS MAX.
POWER GROUND
+VCC
+42V OPERATING VOLTAGE
-42V OPERATING VOLTAGE
OUTPUT: 22.5V RMS 120 WATTS @ 4-OHMS
AUDIO GROUND
+0UTPUT/SPK
PGND
OFFSET NULL
AGND
OUTPUT STAGE BIAS VOLTAGE ADV.

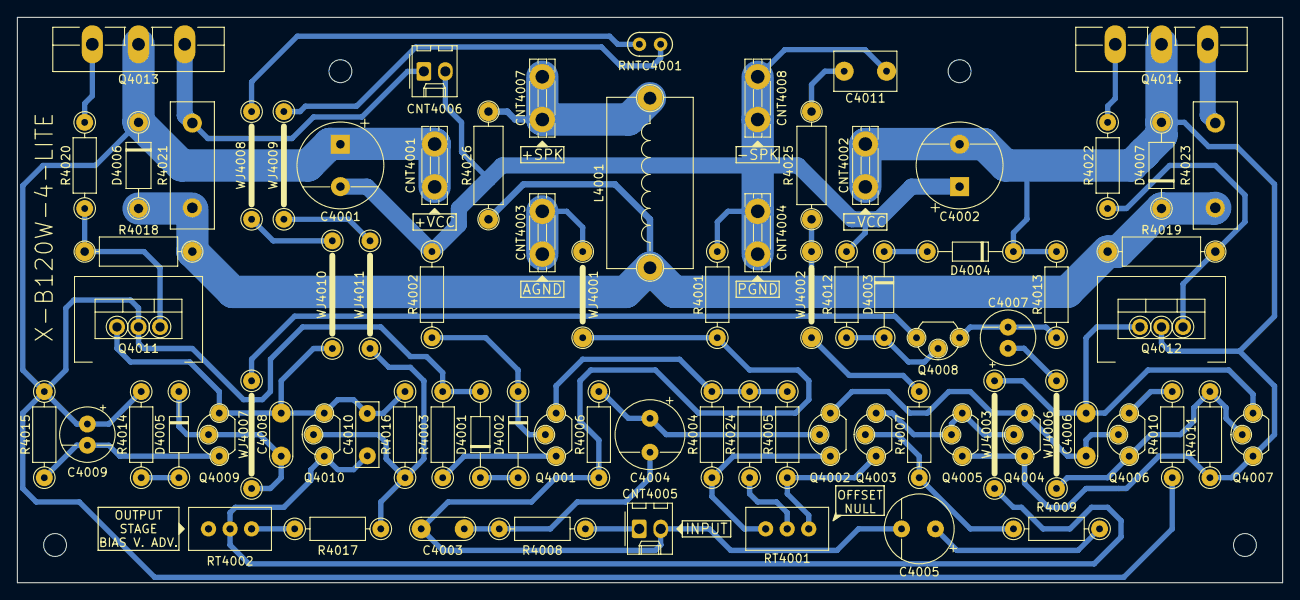
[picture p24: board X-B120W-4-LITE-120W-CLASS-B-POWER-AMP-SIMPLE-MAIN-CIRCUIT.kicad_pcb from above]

Board: 2 copper layers, 149.2 x 66.7 mm, 79 parts (1 on the bottom side), 48 nets.
